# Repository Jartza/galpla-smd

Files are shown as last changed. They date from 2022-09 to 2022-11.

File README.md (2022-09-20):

# Commodore 64 GAL-PLA SMD-version

Commodore 64 PLA replacement using GAL20V8B 28-pin PLCC chips. Based on [PLA20V8](https://www.freepascal.org/~daniel/c64pla/) by Daniël Mantione. Published under permission from Daniël.

This version uses 2 pieces of GAL20V8B chips in 28-pin PLCC package. Due to size constraints, soldering the chips is best done by hot air or hot plate, either using solder paste or tinning the pads and using flux. Fuse map is the same as in DIP-version. In the middle of the board there is a footprint for 0603 (optional) bypass capacitor, 0.1-0.22uF.

Fuse map is unchanged, use original Fuse map from [Daniël's site](https://www.freepascal.org/~daniel/c64pla/)

If you want to order PCBs from PCBWay, follow [this link](https://www.pcbway.com/project/shareproject/Commodore_64_PLA_replacement_d4be5faf.html)

This repository includes the Eagle-files for PCB, and also generated Gerbers.

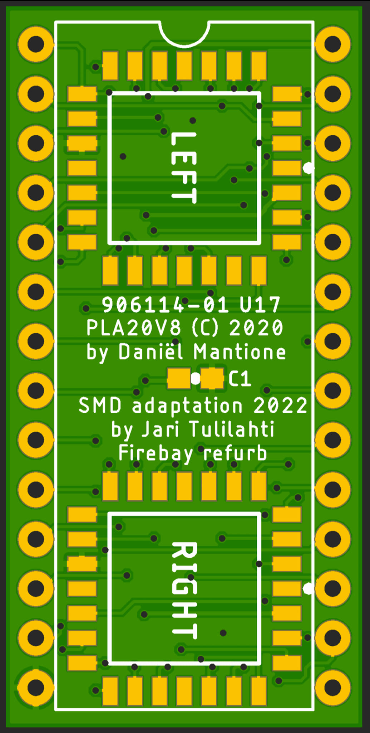
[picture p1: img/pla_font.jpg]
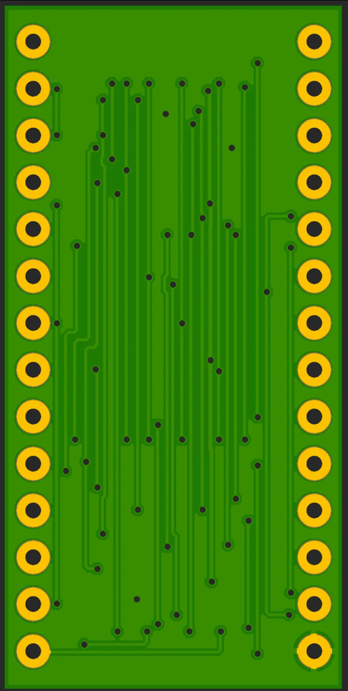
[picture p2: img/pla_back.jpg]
&nbsp;&nbsp;&nbsp;&nbsp;&nbsp;

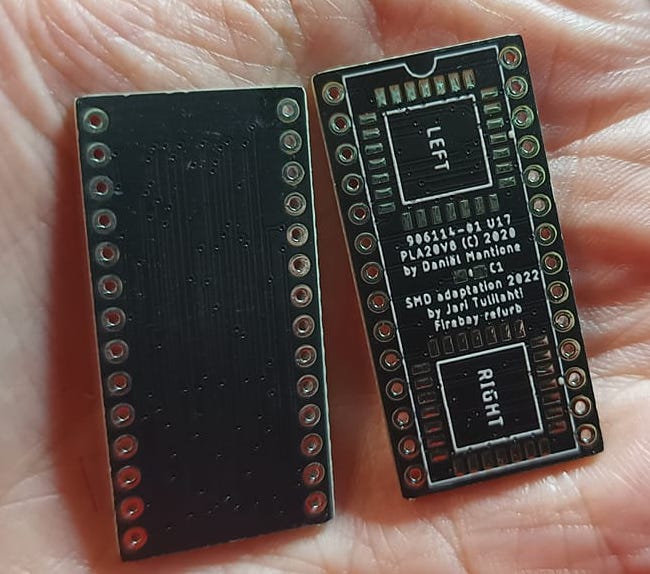
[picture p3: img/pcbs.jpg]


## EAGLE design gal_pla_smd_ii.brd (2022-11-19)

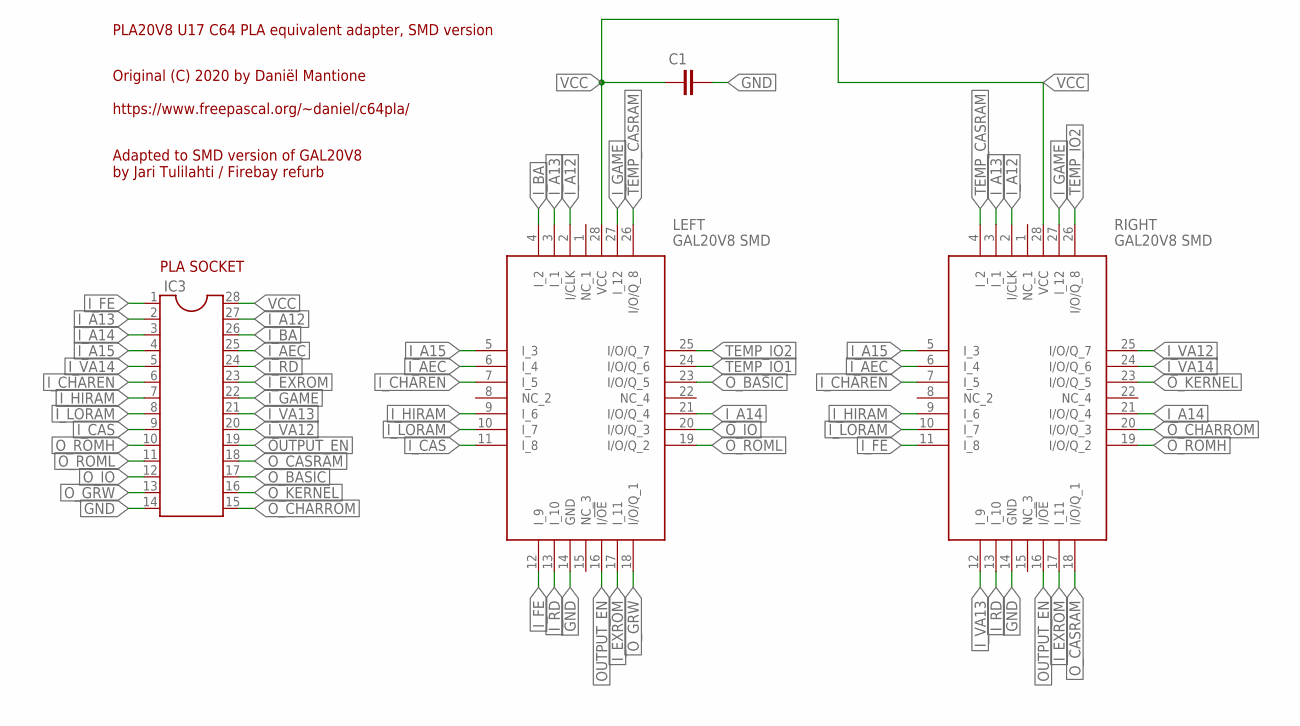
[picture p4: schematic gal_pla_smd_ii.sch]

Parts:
C1: CAP0603-CAP; 0603-CAP
IC3: DIL28; DIL28-6
LEFT: GAL20V8 SMD; PLCC127P1245X1245X457-28N
RIGHT: GAL20V8 SMD; PLCC127P1245X1245X457-28N

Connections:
GND: C1.2, IC3.14, LEFT.14 (GND), RIGHT.14 (GND)
I_A12: IC3.27, LEFT.2 (I/CLK), RIGHT.2 (I/CLK)
I_A13: IC3.2, LEFT.3 (I_1), RIGHT.3 (I_1)
I_A14: IC3.3, LEFT.21 (I/O/Q_4), RIGHT.21 (I/O/Q_4)
I_A15: IC3.4, LEFT.5 (I_3), RIGHT.5 (I_3)
I_AEC: IC3.25, LEFT.6 (I_4), RIGHT.6 (I_4)
I_BA: IC3.26, LEFT.4 (I_2)
I_CAS: IC3.9, LEFT.11 (I_8)
I_CHAREN: IC3.6, LEFT.7 (I_5), RIGHT.7 (I_5)
I_EXROM: IC3.23, LEFT.17 (I_11), RIGHT.17 (I_11)
I_FE: IC3.1, LEFT.12 (I_9), RIGHT.11 (I_8)
I_GAME: IC3.22, LEFT.27 (I_12), RIGHT.27 (I_12)
I_HIRAM: IC3.7, LEFT.9 (I_6), RIGHT.9 (I_6)
I_LORAM: IC3.8, LEFT.10 (I_7), RIGHT.10 (I_7)
I_RD: IC3.24, LEFT.13 (I_10), RIGHT.13 (I_10)
I_VA12: IC3.20, RIGHT.25 (I/O/Q_7)
I_VA13: IC3.21, RIGHT.12 (I_9)
I_VA14: IC3.5, RIGHT.24 (I/O/Q_6)
OUTPUT_EN: IC3.19, LEFT.16 (I/!OE), RIGHT.16 (I/!OE)
O_BASIC: IC3.17, LEFT.23 (I/O/Q_5)
O_CASRAM: IC3.18, RIGHT.18 (I/O/Q_1)
O_CHARROM: IC3.15, RIGHT.20 (I/O/Q_3)
O_GRW: IC3.13, LEFT.18 (I/O/Q_1)
O_IO: IC3.12, LEFT.20 (I/O/Q_3)
O_KERNEL: IC3.16, RIGHT.23 (I/O/Q_5)
O_ROMH: IC3.10, RIGHT.19 (I/O/Q_2)
O_ROML: IC3.11, LEFT.19 (I/O/Q_2)
TEMP_CASRAM: LEFT.26 (I/O/Q_8), RIGHT.4 (I_2)
TEMP_IO1: LEFT.24 (I/O/Q_6)
TEMP_IO2: LEFT.25 (I/O/Q_7), RIGHT.26 (I/O/Q_8)
VCC: C1.1, IC3.28, LEFT.28 (VCC), RIGHT.28 (VCC)

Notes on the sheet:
PLA SOCKET
PLA20V8 U17 C64 PLA equivalent adapter, SMD version
Original (C) 2020 by Daniël Mantione https://www.freepascal.org/~daniel/c64pla/
Adapted to SMD version of GAL20V8 by Jari Tulilahti / Firebay refurb

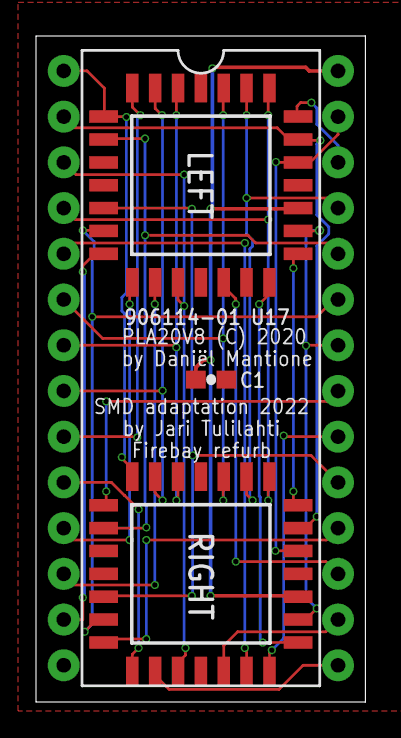
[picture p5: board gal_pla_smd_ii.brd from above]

Board: 2 copper layers, 18.3 x 37.0 mm, 4 parts (0 on the bottom side), 30 nets.

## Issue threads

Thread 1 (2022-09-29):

Boards cannot be manufactured by Aisler

mthiesen, 2022-09-29:
The current gerber files cannot be manufactured by [Aisler](https://aisler.net) because two drills are too close together.

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

I wanted to fix this issue myself but the board in the EAGLE board file is routed completely differently and I do not want to work on an outdated board file. I presume this is an outdated version because drills are intersecting pads and the trace from pin 1 is crooked.

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

Jartza, 2022-11-19:
I just noticed this, for some reason GitHub didn't notify me of new issue, I need to check my settings.

Indeed, I noticed also myself some time ago that I updated intermediate version instead of the updated version - the reason for update was people complaining how hard the previous one was to hand-solder, so I extended the pads a little and re-traced the board.

Both the old version (in PCBWAY) and the latest update (Oct 27) has been verified working.

Jartza, 2022-11-19:
Looks like there still was one drill too close for Aisler, I made a small update.

Jartza, 2022-11-19:
After last update, Aisler automatic tests seem to also be happy, so closing this one, thanks for the heads up.

Closed 2022-11-19.

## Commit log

2022-10-27 Update to bigger pads for easier hand-soldering
    [gal_pla_smd_ii.brd, gal_pla_smd_ii.sch]
2022-10-27 Update gerbers
2022-11-19 Update to latest
    [gal_pla_smd_ii.brd]

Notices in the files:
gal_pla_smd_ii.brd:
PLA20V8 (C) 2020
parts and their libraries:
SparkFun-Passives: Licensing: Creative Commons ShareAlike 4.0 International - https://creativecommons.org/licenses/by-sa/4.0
